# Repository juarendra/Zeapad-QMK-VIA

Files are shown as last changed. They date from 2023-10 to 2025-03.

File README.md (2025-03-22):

# ZEAPAD-QMK-VIA
Zeapad Encoder adalah sebuah macropad yang dmemiliki 14 key dengan Switch MX dan  2 buah Rotary encoder di ujung kanan atas dan ujung kiri atas.

Rotary encoder pada umummnya digunakan untuk melakukan perubahan nilai yang bervariable seperti volume atau brightness.
dengan menyesuaikan firmware sebelumnya. sekarang anda dapat mengedit fungsi dari Rotary Encoder sesuai dengan keinginan anda pada Software VIA Configurator 

support untuk Windows, Linux dan Mac OS

## Table of Content
* [Product Specsification](#product-specsification)
* [Download VIA](#download-via)
* [Autodetect on VIA or you can load JSON File](#Autodetect-on-VIA-or-you-can-load-JSON-File)
* [Link Keycode QMK](#Link-keycode-qmk)
* [Tutorial VIA Usage](#tutorial-via-usage)
* [Cara Setting Knob](#cara-setting-knob)
* [How To use MACRO](#how-to-use-macro)
* [Preview Hardware](#preview-hardware)
* [Preview VIA](#preview-via)
* [Cara Update/Upgrade Firmware](#cara-update/upgrade-firmware)
* [MIDI2LR Usage](#midi2lr-usage)
* [Documentation](#documentation)
  * [Pinout Diagram](#pinout-diagram)
  * [Dimension](#dimension)
  * [BOM](#bom)
  * [Schematic](#schematic)
  * [Example Program](#examples-program)
* [FAQ](#FAQ)

## Product Specsification
- STM32F401 as Microcontroller
- QMK Firmware
- Support VIA, all key and knob can proggrammed
- RGB Underglow
- 4x Layer 
- 16x Switch or 15x Switch + 1 Encoder or 14x Switch + 2 Encoder
- Hotswap Switch
- 3D Case 
- USB type C

## Download VIA
Link Download VIA(Pilih sesuai OS) : https://github.com/the-via/releases/releases
VIA WEB VERSION : https://usevia.app/

## Autodetect on VIA or you can load JSON File
for auto detect on VIA, you just need connect the macropad to your PC and Open VIA in web or apps
or you can connect VIA manually with this step
- Connect your macropad to PC
- Open VIA
- In Tab Setting, enable "Show Design Tab"
- Open Design Tab
- Load file with name "zeapad_via_definitions.json" 
- Open Configure Tab to setting your macropad
- If nothing happend , do it again from first

## Link Keycode QMK
- mouse : https://github.com/qmk/qmk_firmware/blob/master/docs/feature_mouse_keys.md
- keyboard : https://github.com/qmk/qmk_firmware/blob/master/docs/keycodes.md

## Tutorial VIA Usage
- https://docs.keeb.io/via

## Cara Menggunakan Tap Hold dan Tap Reapeatly
### Tap Hold
- Anda perlu mendaftakan satu tombol dahulu yang aakn digunakan sebagai trigger tap hold
- Pilih satu key yang akan digunakkan sebagi trigger Tap Hold
- Pada Setting keymap masuk ke tab "Special" dan pilih "Any Key"
- Masukan "0x7C59" dan tekan OK
- Anda telah memiliki trigger untuk Tap Hold
- Untuk menggunakannya anda dapat menekan dahulu trigger Tap Hold
- lalu tekan tombol lainnya yang ingin di hold terus
- maka tombol tersebut akan tertekan terus sampai anda menekan tombol itu kembali untuk menghentikannya

Note: Untuk Tap hold hanya mendukung tombol biasa seperti tombol "QWERTY"

### Tap Repeatly
- Anda perlu mendaftakan satu tombol dahulu yang aakn digunakan sebagai trigger Tap Repeatly
- Pilih satu key yang akan digunakkan sebagi trigger Tap Repeatly
- Pada Setting keymap masuk ke tab "Special" dan pilih "Any Key"
- Masukan "CUSTOM(85)" dan tekan OK
- Anda telah memiliki trigger untuk Tap Repeatly
- Untuk menggunakannya anda dapat menekan dahulu trigger Tap Repeatly
- lalu tekan tombol lainnya yang ingin di tekan dengan mode Repeatly
- maka tombol tersebut akan tertekan Repeatly dengan delay 100ms sampai anda menekan tombol itu kembali untuk menghentikannya

Note: Untuk Tap Repeatly hanya mendukung tombol biasa seperti tombol "QWERTY" dan "any key"

## Cara Setting Knob
- Untuk melakukan setting di knob perlu memasukan command berupa keycode qmk, Jadi cara nya sama dengan melakuykan setting dengan Any key seperti petunjuk pada link berikut: 
https://docs.keeb.io/via

Here's some examples:

- LALT(KC_TAB) - Sends Alt-Tab
- LCTL(KC_C) - Sends Ctrl-C
- LGUI(KC_C) - Sends Cmd-C or Win-C
- LSFT(LCTL(KC_END)) - Sends Shift-Ctrl-End
- MO(1) - Momentarily turn on layer 1
- LCA(KC_DEL) - Sends Ctrl-Alt-Del
- MT(MOD_RSFT, KC_ENT) - Sends Shift if held, Enter if tapped
- MACRO (0) - macro 0

## How To use MACRO
you can read on [this file](https://github.com/juarendra/STREAMPAD-QMK-VIA/blob/main/DOC/MACRO%20VIA%20USAGE.pdf)
or you can read on this [web](https://www.keychron.com/blogs/archived/how-to-use-via-to-program-your-keyboard)
or you can see video [youtube](https://youtu.be/GtSeo69Y0Zw)

## Preview Hardware
<p align="center">
  
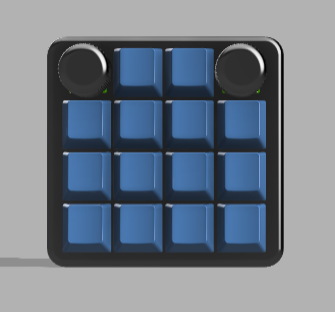
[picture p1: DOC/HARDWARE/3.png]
  
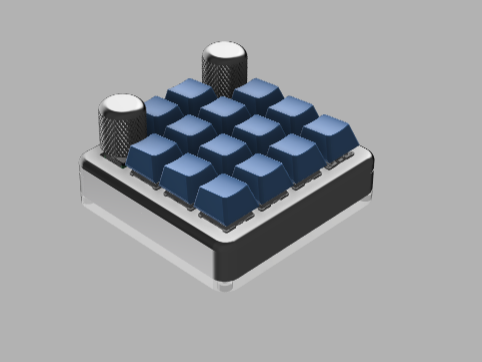
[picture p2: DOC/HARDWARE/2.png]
  
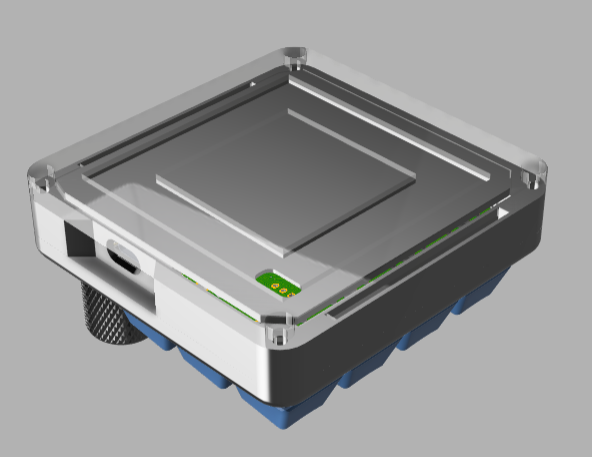
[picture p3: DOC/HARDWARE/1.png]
  
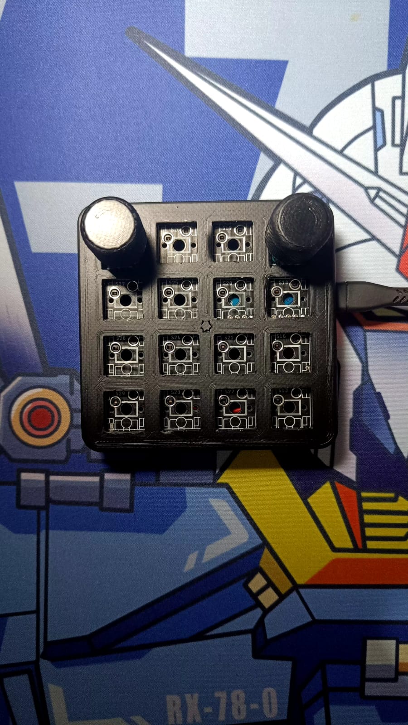
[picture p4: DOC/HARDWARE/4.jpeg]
  
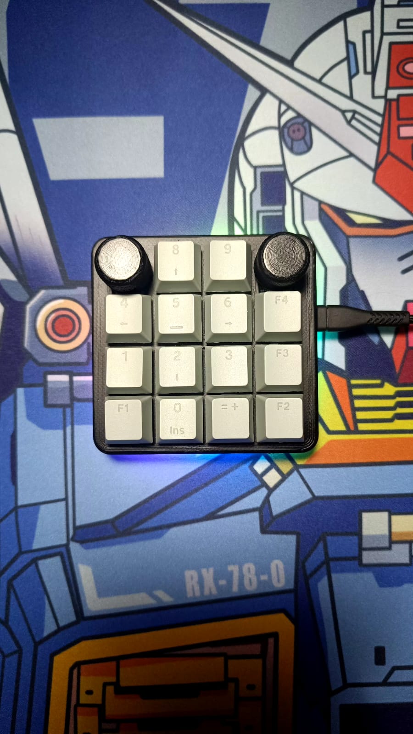
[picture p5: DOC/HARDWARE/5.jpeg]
  
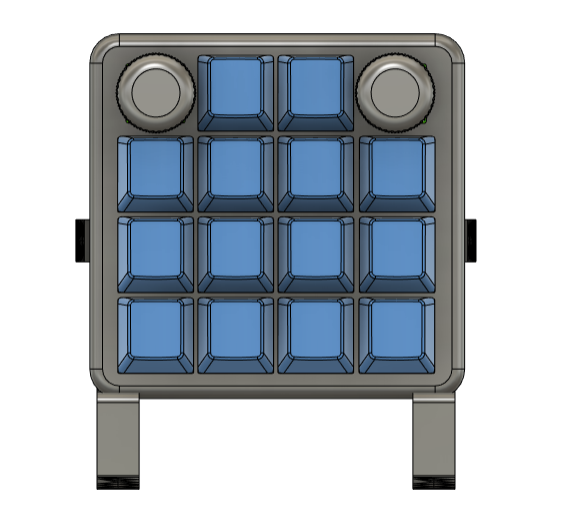
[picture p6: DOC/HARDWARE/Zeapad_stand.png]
  
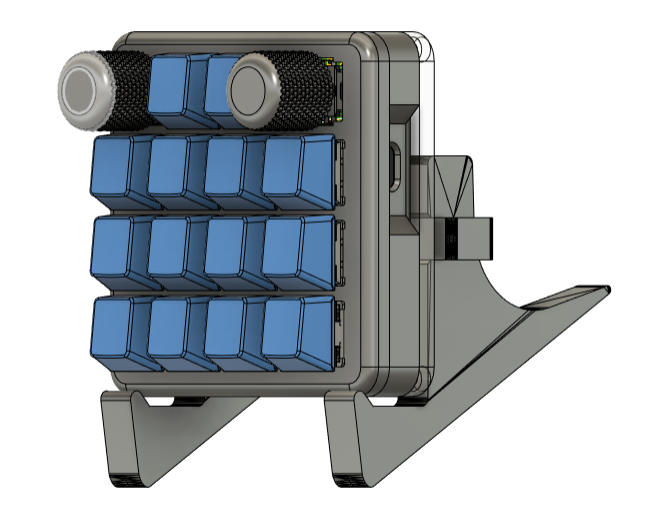
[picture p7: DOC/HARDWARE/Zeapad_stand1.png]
  
</p>

## Preview VIA
Positron Electronic on YouTube (http://www.youtube.com/watch?v=qvMjg3LCvkY "zeapad stm32")

## Cara Update/Upgrade Firmware
- Siapkan dahulu macropad, kabel usb dan firmware yang ingin di update/upgrade ke macropad anda
- Siapkan Firmware yang akan digunakan untuk update/upgrade
- Download Software QMK Toolbox di [link berikut](https://github.com/qmk/qmk_toolbox/releases)
- Install Software QMK Toolbox, Install Semua drivernya. setelah siap anda dapat meload Firmware yang seblumnya. Lalu Centang Auto-Flash seperti gambar dibawah
<p align="center">
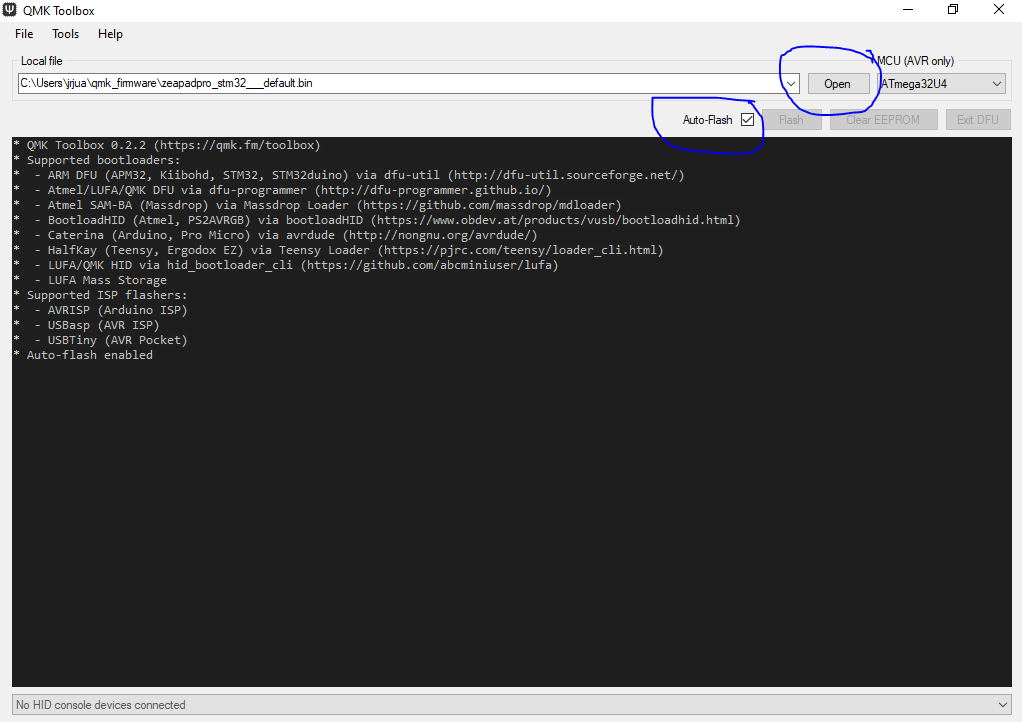
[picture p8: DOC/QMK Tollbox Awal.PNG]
  
</p>

- Colok kabel ujung usb type C ke macropad tanpa mencolokannya dahulu ke USB PC anda
- Tekan dan tahan tombol/knob yang berada di ujung atas kiri. lalu colokan Ujung USB yang sebelum ke USB PC anda sambil tetap menahan tombol sebelum nya sebentar
- Setelah ada bunyi/notif USB masuk. anda dapat melepaskan tombol/knobnya
- Maka secara otomatis macropad akan terflash. jika selesai maka tampilan QMK toolbox akan seperti gambar dibawah
<p align="center">
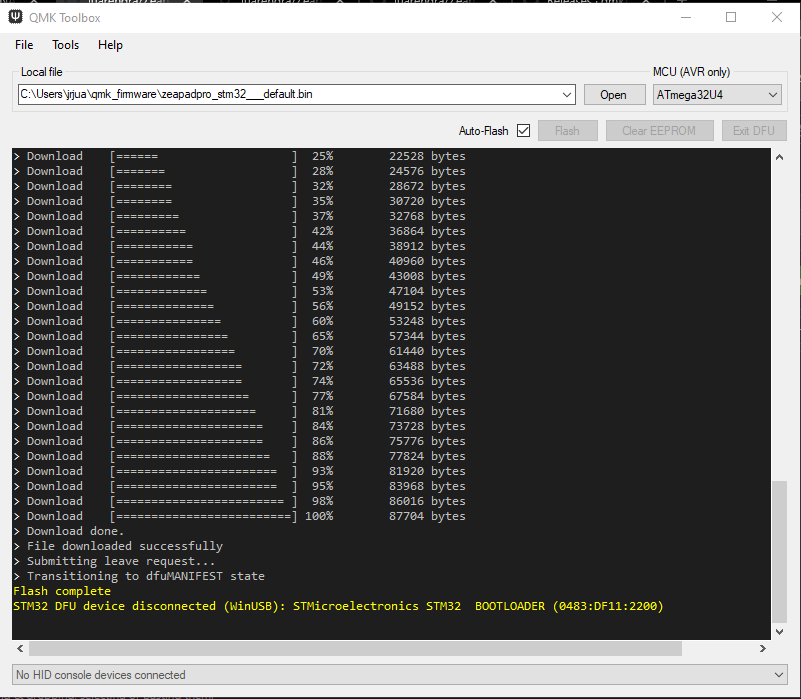
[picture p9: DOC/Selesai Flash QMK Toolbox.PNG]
  
</p>

## MIDI2LR Usage
MIDI2LR adalah extension dari Adobe Ligtroom yang berguna untuk mengkonversi inputan MIDI dari Midi controller menjadi perintah perintah Lightroom. Salah satu fitur QMK adalah dapat dijadikan sebuah midi controller, sehingga pada dibutalah firmware QMK yang dapat mendukung fitur midi controller pada macropad ZEAPAD PRO tersebut. 

untuk mempelajari penggunaan MIDI2LR and dapat melihat VIDEO [berikut](https://www.youtube.com/watch?v=VDSN_Vz6U04&t=319s).

untuk menggunakan zeapad pro sebagai midi controller anda dapat memasukan keycode midi controller yang ada di link [berikut](https://docs.qmk.fm/features/midi) ke ANY KEY pada aplikasi VIA, seprti contohnya keycode "MI_C" untuk mengirimkan note C, "MI_D" untuk mengirimkan note D

Untuk mengirimkan CC atau Control Change anda dapat memasukan keycode pada TAB "Custom" di aplikasi VIA seperti gambar dibawah

<p align="center">
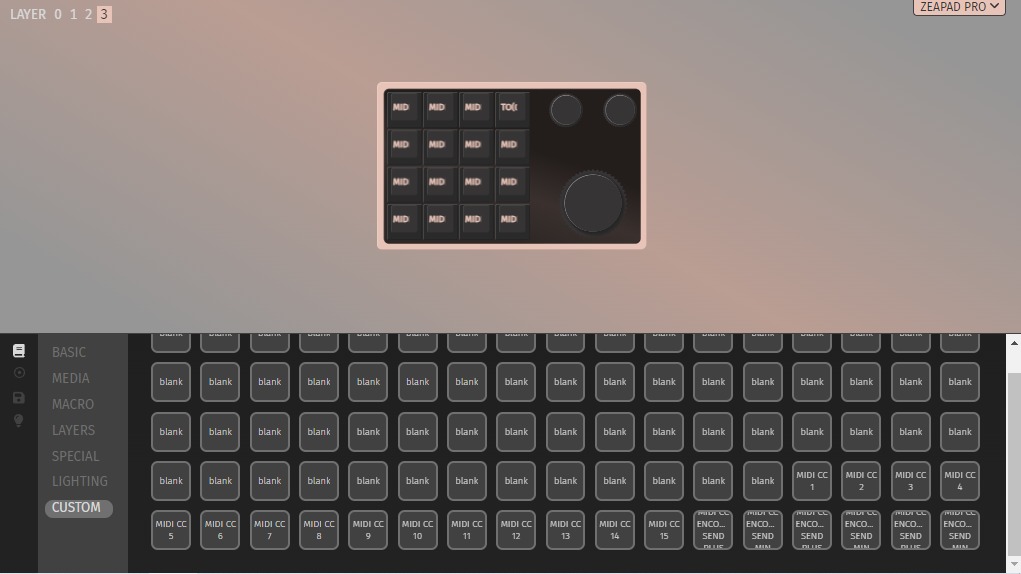
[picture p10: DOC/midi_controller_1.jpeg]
  
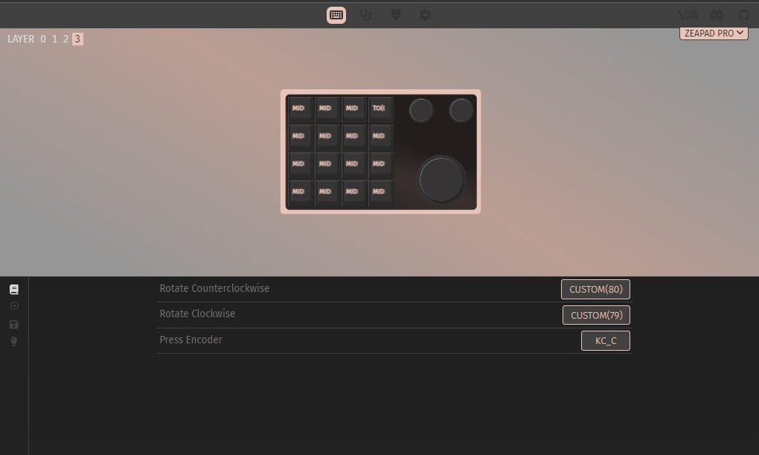
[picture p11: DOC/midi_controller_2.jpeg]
  
</p>

berikut merupakan penjelasan keycode keycode yang ada pada TAB "Custom". abaikan keycode dengan nama "blank". Semua keycode dibawah ini sudah di lakukan preset di layer ke 4

| Keycode | Function |  Penjelasana | 
| --- | --- | --- |
| MIDI CC 1  | Memilih CC 1 untuk encoder 1, CC 16 untuk encoder 2 dan CC 31 untuk encoder 3| dengan menekan keycode ini anda akan memilihi CC tersebut sehingga pada saat anda memutar knob/encoder yang berkaitan maka akan mengirimkan CC yang terpilih sebelumnya sesuai dengan encoder/knob yang di putar|
| MIDI CC 2  | Memilih CC 2 untuk encoder 1, CC 17 untuk encoder 2 dan CC 32 untuk encoder 3| dengan menekan keycode ini anda akan memilihi CC tersebut sehingga pada saat anda memutar knob/encoder yang berkaitan maka akan mengirimkan CC yang terpilih sebelumnya sesuai dengan encoder/knob yang di putar|
| MIDI CC 3  | Memilih CC 3 untuk encoder 1, CC 18 untuk encoder 2 dan CC 33 untuk encoder 3| dengan menekan keycode ini anda akan memilihi CC tersebut sehingga pada saat anda memutar knob/encoder yang berkaitan maka akan mengirimkan CC yang terpilih sebelumnya sesuai dengan encoder/knob yang di putar|
| MIDI CC 4  | Memilih CC 4 untuk encoder 1, CC 19 untuk encoder 2 dan CC 34 untuk encoder 3| dengan menekan keycode ini anda akan memilihi CC tersebut sehingga pada saat anda memutar knob/encoder yang berkaitan maka akan mengirimkan CC yang terpilih sebelumnya sesuai dengan encoder/knob yang di putar|
| MIDI CC 5  | Memilih CC 5 untuk encoder 1, CC 20 untuk encoder 2 dan CC 35 untuk encoder 3| dengan menekan keycode ini anda akan memilihi CC tersebut sehingga pada saat anda memutar knob/encoder yang berkaitan maka akan mengirimkan CC yang terpilih sebelumnya sesuai dengan encoder/knob yang di putar|
| MIDI CC 6  | Memilih CC 6 untuk encoder 1, CC 21 untuk encoder 2 dan CC 36 untuk encoder 3|  dengan menekan keycode ini anda akan memilihi CC tersebut sehingga pada saat anda memutar knob/encoder yang berkaitan maka akan mengirimkan CC yang terpilih sebelumnya sesuai dengan encoder/knob yang di putar|
| MIDI CC 7  | Memilih CC 7 untuk encoder 1, CC 22 untuk encoder 2 dan CC 37 untuk encoder 3|  dengan menekan keycode ini anda akan memilihi CC tersebut sehingga pada saat anda memutar knob/encoder yang berkaitan maka akan mengirimkan CC yang terpilih sebelumnya sesuai dengan encoder/knob yang di putar|
| MIDI CC 8  | Memilih CC 8 untuk encoder 1, CC 23 untuk encoder 2 dan CC 38 untuk encoder 3|  dengan menekan keycode ini anda akan memilihi CC tersebut sehingga pada saat anda memutar knob/encoder yang berkaitan maka akan mengirimkan CC yang terpilih sebelumnya sesuai dengan encoder/knob yang di putar|
| MIDI CC 9  | Memilih CC 9 untuk encoder 1, CC 24 untuk encoder 2 dan CC 39 untuk encoder 3|  dengan menekan keycode ini anda akan memilihi CC tersebut sehingga pada saat anda memutar knob/encoder yang berkaitan maka akan mengirimkan CC yang terpilih sebelumnya sesuai dengan encoder/knob yang di putar|
| MIDI CC 10  | Memilih CC 10 untuk encoder 1, CC 25 untuk encoder 2 dan CC 40 untuk encoder 3|  dengan menekan keycode ini anda akan memilihi CC tersebut sehingga pada saat anda memutar knob/encoder yang berkaitan maka akan mengirimkan CC yang terpilih sebelumnya sesuai dengan encoder/knob yang di putar|
| MIDI CC 11  | Memilih CC 11 untuk encoder 1, CC 26 untuk encoder 2 dan CC 41 untuk encoder 3|  dengan menekan keycode ini anda akan memilihi CC tersebut sehingga pada saat anda memutar knob/encoder yang berkaitan maka akan mengirimkan CC yang terpilih sebelumnya sesuai dengan encoder/knob yang di putar|
| MIDI CC 12  | Memilih CC 12 untuk encoder 1, CC 27 untuk encoder 2 dan CC 42 untuk encoder 3|  dengan menekan keycode ini anda akan memilihi CC tersebut sehingga pada saat anda memutar knob/encoder yang berkaitan maka akan mengirimkan CC yang terpilih sebelumnya sesuai dengan encoder/knob yang di putar|
| MIDI CC 13  | Memilih CC 13 untuk encoder 1, CC 28 untuk encoder 2 dan CC 43 untuk encoder 3|  dengan menekan keycode ini anda akan memilihi CC tersebut sehingga pada saat anda memutar knob/encoder yang berkaitan maka akan mengirimkan CC yang terpilih sebelumnya sesuai dengan encoder/knob yang di putar|
| MIDI CC 14  | Memilih CC 14 untuk encoder 1, CC 29 untuk encoder 2 dan CC 44 untuk encoder 3|  dengan menekan keycode ini anda akan memilihi CC tersebut sehingga pada saat anda memutar knob/encoder yang berkaitan maka akan mengirimkan CC yang terpilih sebelumnya sesuai dengan encoder/knob yang di putar|
| MIDI CC 15  | Memilih CC 15 untuk encoder 1, CC 30 untuk encoder 2 dan CC 45 untuk encoder 3|  dengan menekan keycode ini anda akan memilihi CC tersebut sehingga pada saat anda memutar knob/encoder yang berkaitan maka akan mengirimkan CC yang terpilih sebelumnya sesuai dengan encoder/knob yang di putar|
| MIDI CC ENCODER1 SEND PLUS  | Mengirimkan CC yang terpilih untuk encoder/knob 1 dengan value 65 | keycode ini perlu di daftarkan ke encoder/knob pada orientasi clockwise agar dapat mengatur menaikan value CC yang sesuai di encoder/ knob 1 |
| MIDI CC ENCODER1 SEND MIN  | Mengirimkan CC yang terpilih untuk encoder/knob 1 dengan value 63 | keycode ini perlu di daftarkan ke encoder/knob pada orientasi anticlockwise agar dapat mengatur menaikan value CC yang sesuai di encoder/ knob 1 |
| MIDI CC ENCODER2 SEND PLUS  | Mengirimkan CC yang terpilih untuk encoder/knob 2 dengan value 65 | keycode ini perlu di daftarkan ke encoder/knob pada orientasi clockwise agar dapat mengatur menaikan value CC yang sesuai di encoder/ knob 2 |
| MIDI CC ENCODER2 SEND MIN  | Mengirimkan CC yang terpilih untuk encoder/knob 2 dengan value 63 | keycode ini perlu di daftarkan ke encoder/knob pada orientasi anticlockwise agar dapat mengatur menaikan value CC yang sesuai di encoder/ knob 2  |
| MIDI CC ENCODER3 SEND PLUS  | Mengirimkan CC yang terpilih untuk encoder/knob 3 dengan value 65 | keycode ini perlu di daftarkan ke encoder/knob pada orientasi clockwise agar dapat mengatur menaikan value CC yang sesuai di encoder/ knob 3 |
| MIDI CC ENCODER3 SEND MIN  | Mengirimkan CC yang terpilih untuk encoder/knob 3 dengan value 63| keycode ini perlu di daftarkan ke encoder/knob pada orientasi anticlockwise agar dapat mengatur menaikan value CC yang sesuai di encoder/ knob 2 |

## Documentation
### Pinout Diagram
### Dimension
[Dimension File](https://github.com/juarendra/Zeapad-QMK-VIA/blob/main/HARDWARE/zeapad_dimension.pdf)
### BOM
### Schematic
[Schematic File](https://github.com/juarendra/Zeapad-QMK-VIA/blob/main/HARDWARE/zeapad_stm32.pdf)
### Example Program
[Example Firmware](https://github.com/juarendra/Zeapad-QMK-VIA/tree/main/FIRMWARE)
## FAQ

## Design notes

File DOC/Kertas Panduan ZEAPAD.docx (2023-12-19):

1. Untuk Documentasi Lengkapnya anda dapat membuka link google drive dibawah ini

https://shorturl.at/cdsA3

2. Lihat dahulu video untuk mengetahui cara pengunaan macropad dengan software VIA
3. Fungsi file file di google drive
a. Link Keycode.txt = berisi link yang menunjukan list keycode yang dapat digunakan dalam melakukan setting keymap
b. TUTORIAL MACRO ON VIA CONFIGURATOR.txt = berisi link tutorial cara membuat macro di software via
c. LINK TUTORIAL PENGGUNAAN.txt = berisi link video tutorial penggunaan
d. TUTORIAL MEMBUAT TOMBOL PINDAH LAYER.txt = berisi panduan untuk merubah fungsi tombol sebagai trigger memindahkan layer
e. zeapad_via_definitions.json = File json yang perlu dimasukkan ke VIA

Untuk panduan lainnya menggunakan software via ada dapat membacanya disini https://docs.keeb.io/via

Pada via hanya dapat menyimpan maks 15 macro di seluruh layer. Ada beberapa trik untuk memaksimalkannya. Jika macro anda hanya kombinasi sederhana seperti CTRL + ALT + DEL maka anda dapat menggunakan fitur ANY keys pada tab special seperti dibawah

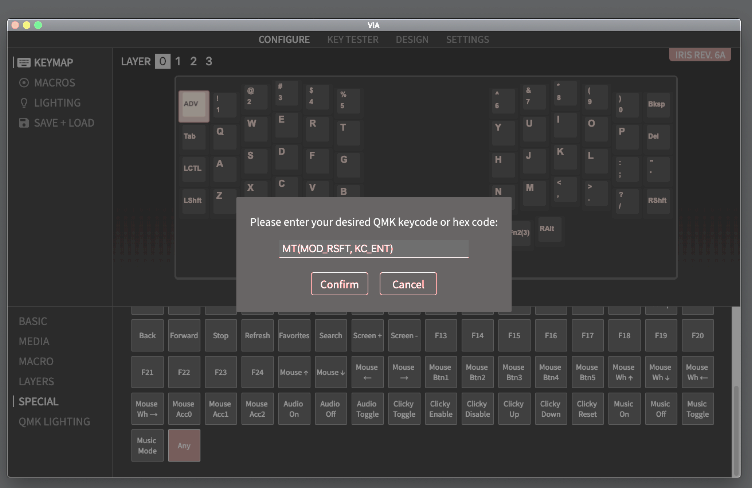
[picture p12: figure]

Untuk jelasnya anda dapat membacanya di https://docs.keeb.io/via

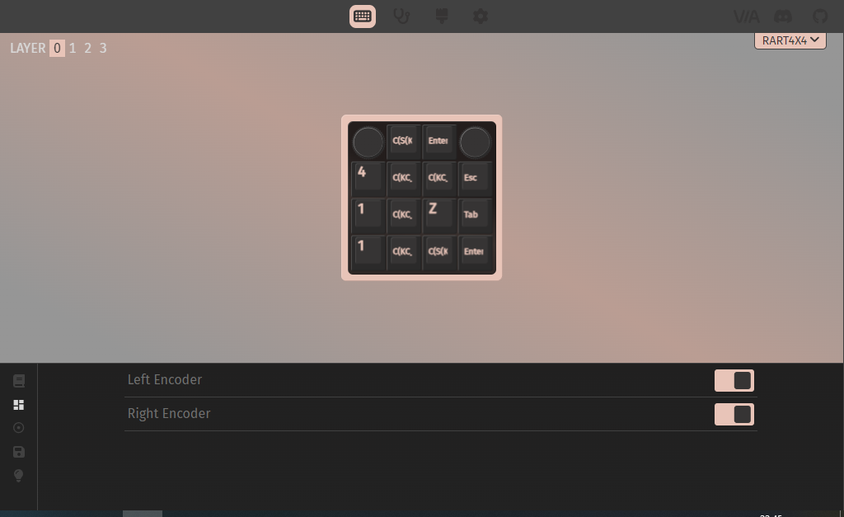
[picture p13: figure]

Anda harus mengaktiflkan kedua encoder untuk melakukan setting pada putaran encoder seperti pada gambar

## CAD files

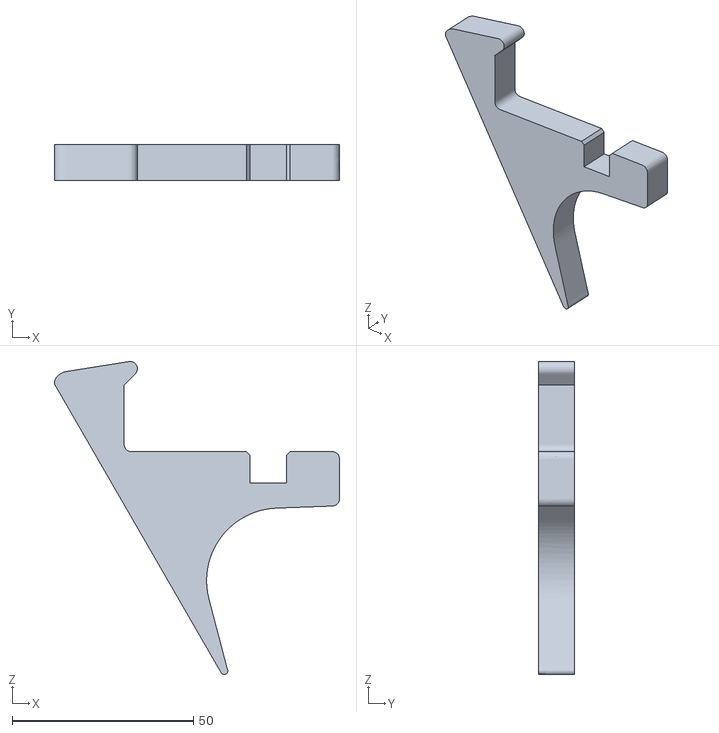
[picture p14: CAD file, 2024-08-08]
HARDWARE/Case/stand/Revised_Keyboard_Stand_Legs_v02 (5).stl
78.6 x 10.0 x 86.3

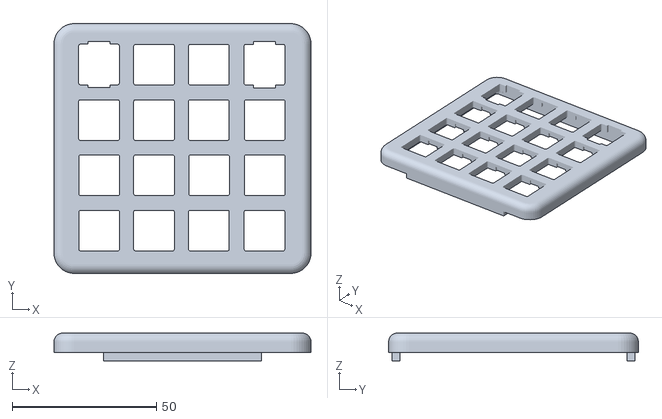
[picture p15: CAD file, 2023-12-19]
HARDWARE/Case/top_zeapad_stm32.stl
89.0 x 86.5 x 9.66

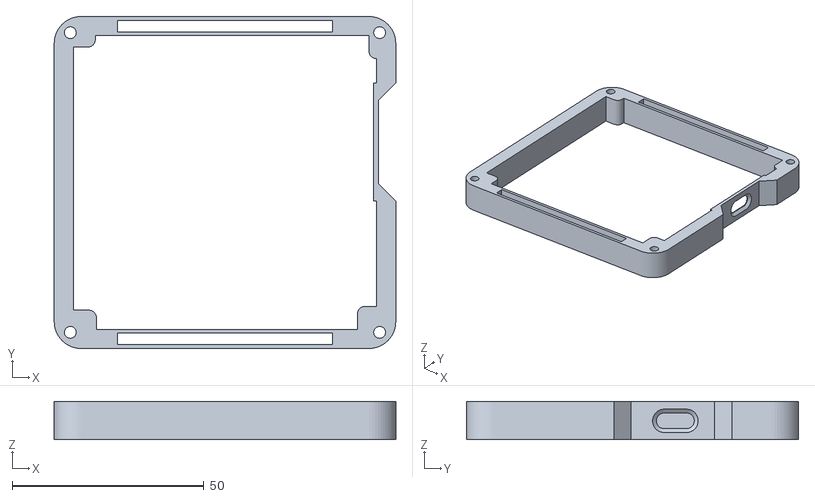
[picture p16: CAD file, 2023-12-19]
HARDWARE/Case/middle_zeapad_stm32.stl
89.0 x 86.5 x 10.0

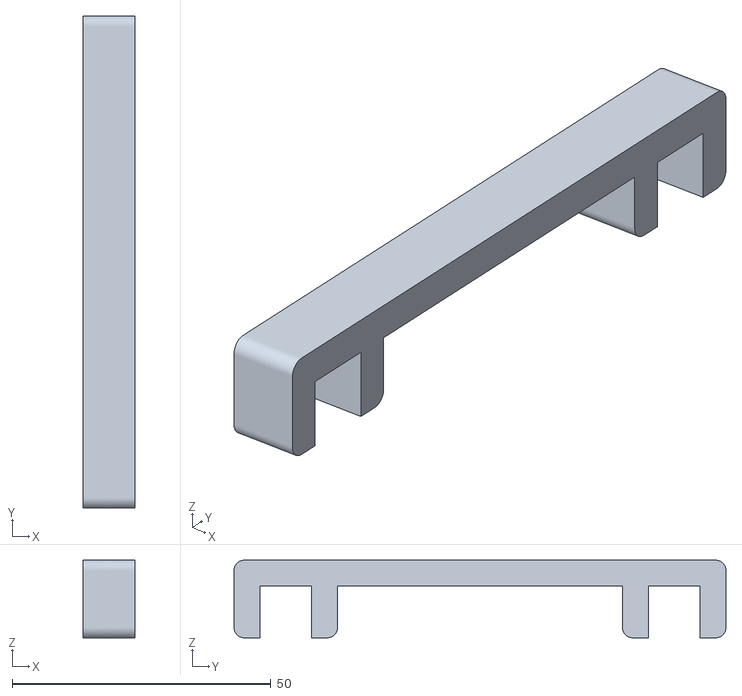
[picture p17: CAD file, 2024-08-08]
HARDWARE/Case/stand/Support (1) (1).stl
10.0 x 95.0 x 15.0

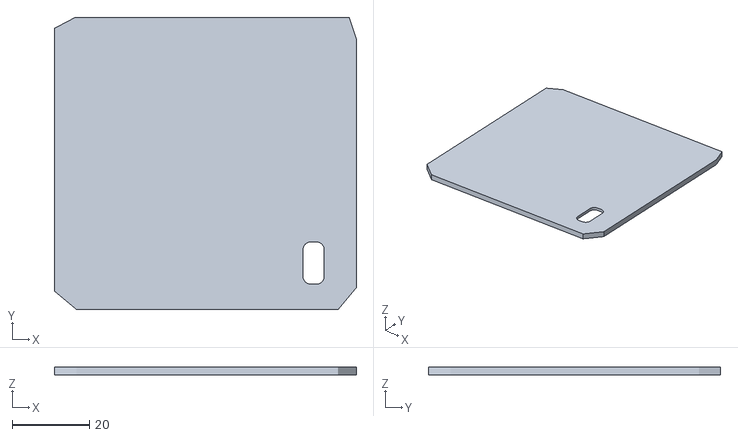
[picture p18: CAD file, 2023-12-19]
HARDWARE/Case/braket_led_stm32.stl
78.2 x 75.7 x 2.00

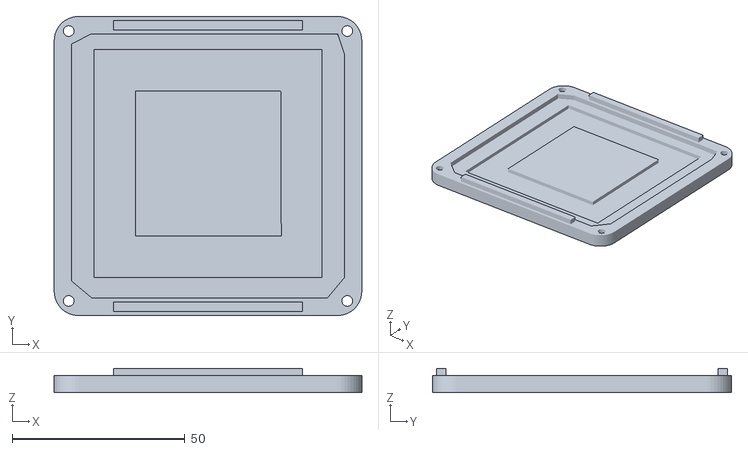
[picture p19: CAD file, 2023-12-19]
HARDWARE/Case/bottom_zeapad_stm32.stl
89.0 x 86.5 x 7.00

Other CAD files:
HARDWARE/Case/stand/Revised_Keyboard_Stand_Legs_v02 (5) (1).stl

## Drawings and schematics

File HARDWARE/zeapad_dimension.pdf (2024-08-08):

86.5
46.01 35.51

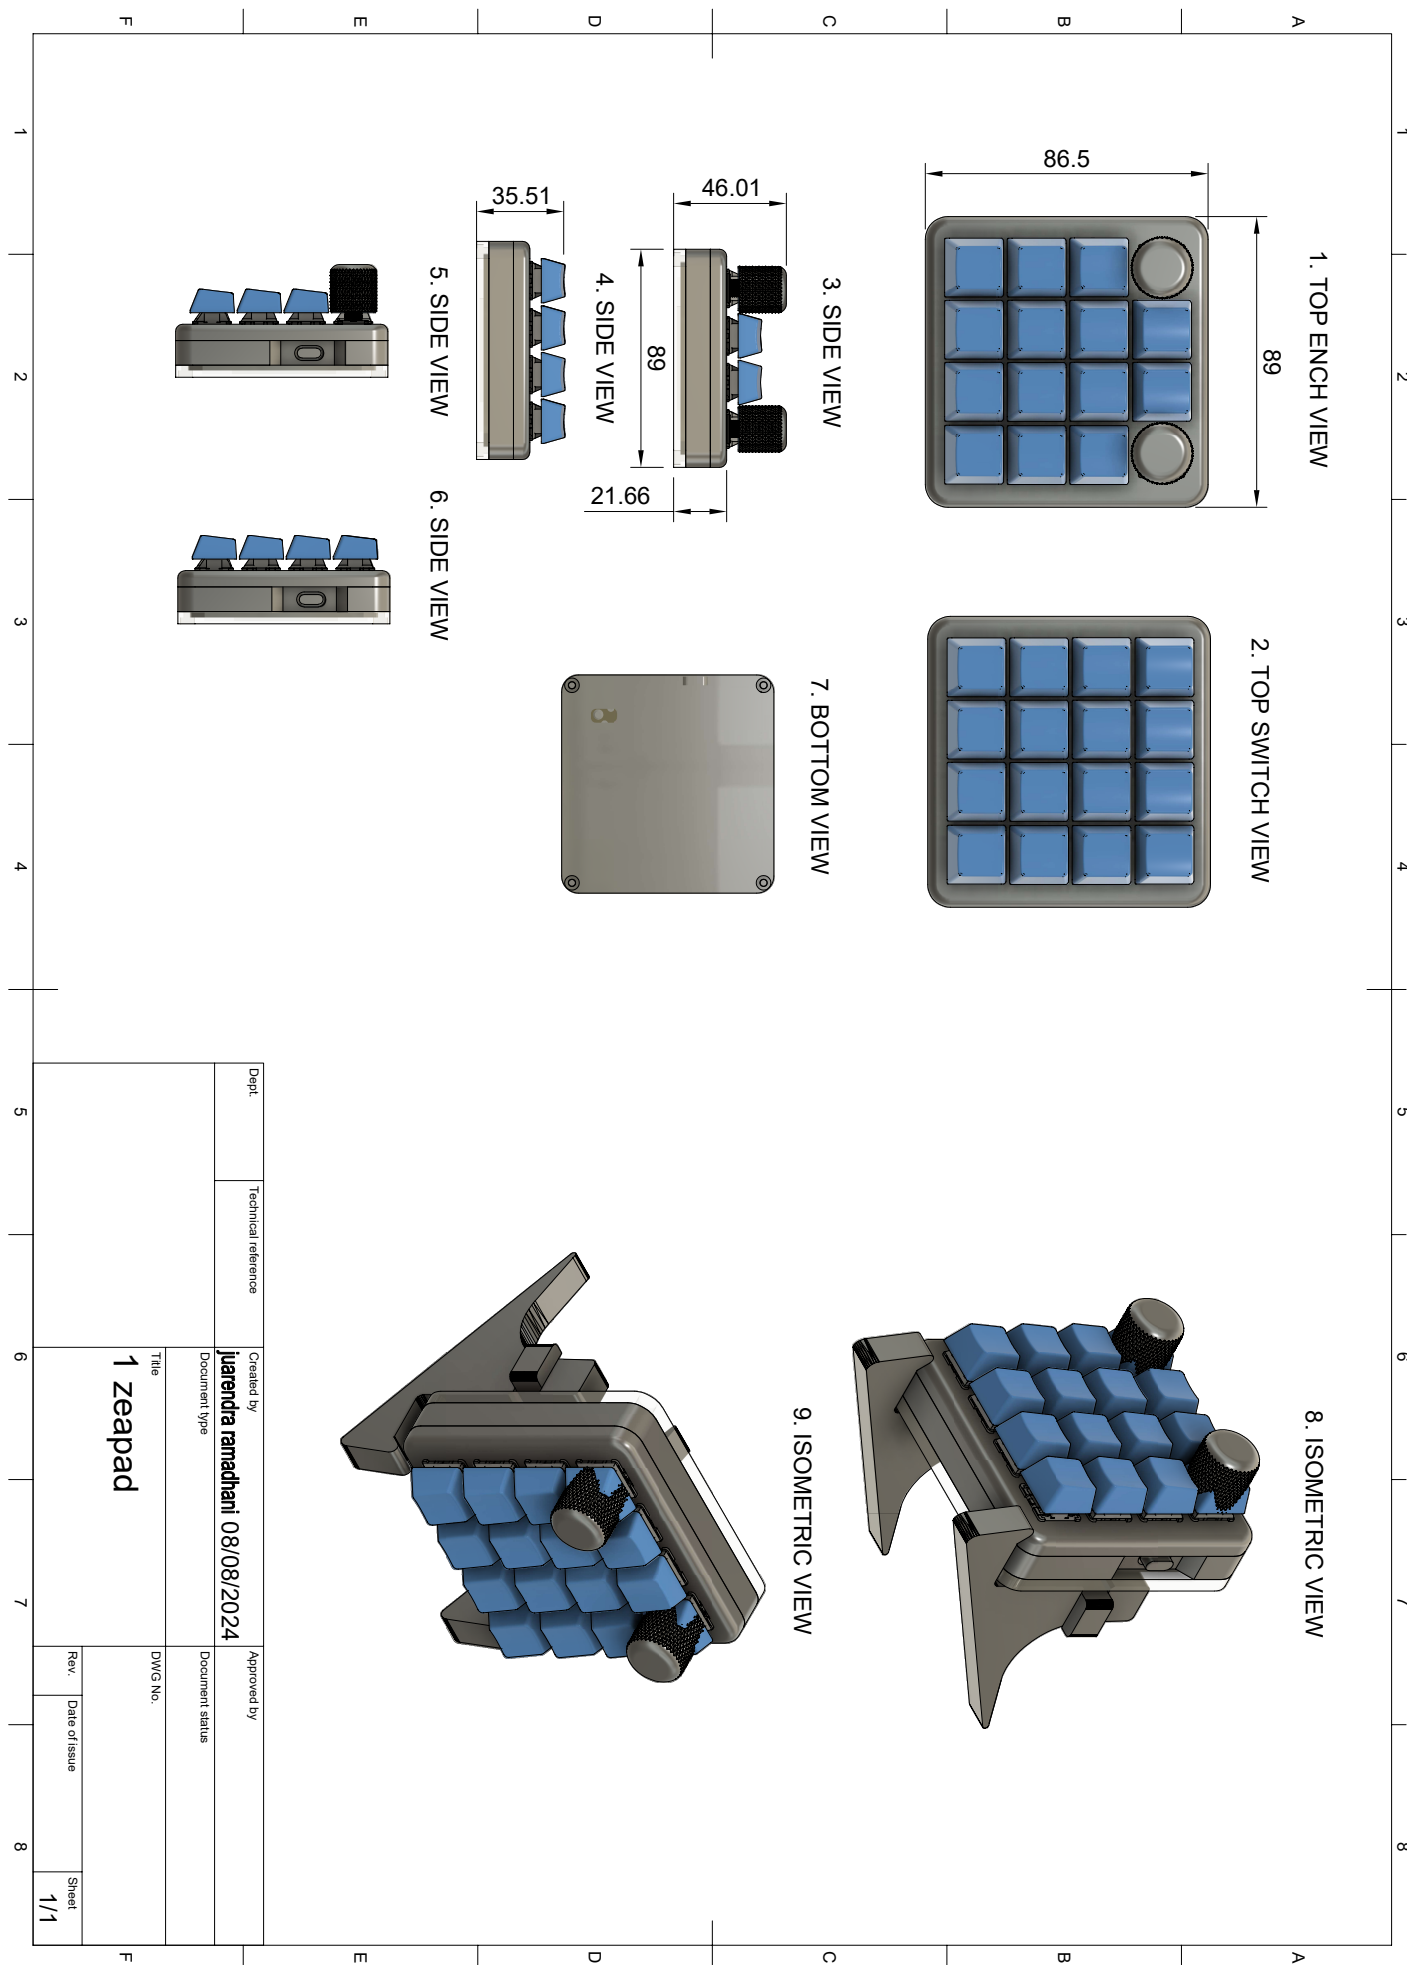
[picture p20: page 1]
1. TOP ENCH VIEW 2. TOP SWITCH VIEW ⁵. SIDE VIEW 6. SIDE VIEW; 4. SIDE VIEW; 3. SIDE VIEW 7. BOTTOM VIEW 9. ISOMETRIC VIEW; 8. ISOMETRIC VIEW

1 A 2 3 4 5 6 7 8 1 2 3 4 5 6 7 8 FEDCB FEDCBA Dept. Technical reference Created by Approved by Title DWG No. Document type Document status Rev. Date of issue Sheet 08/08/2024 1/1 1 zeapad 89

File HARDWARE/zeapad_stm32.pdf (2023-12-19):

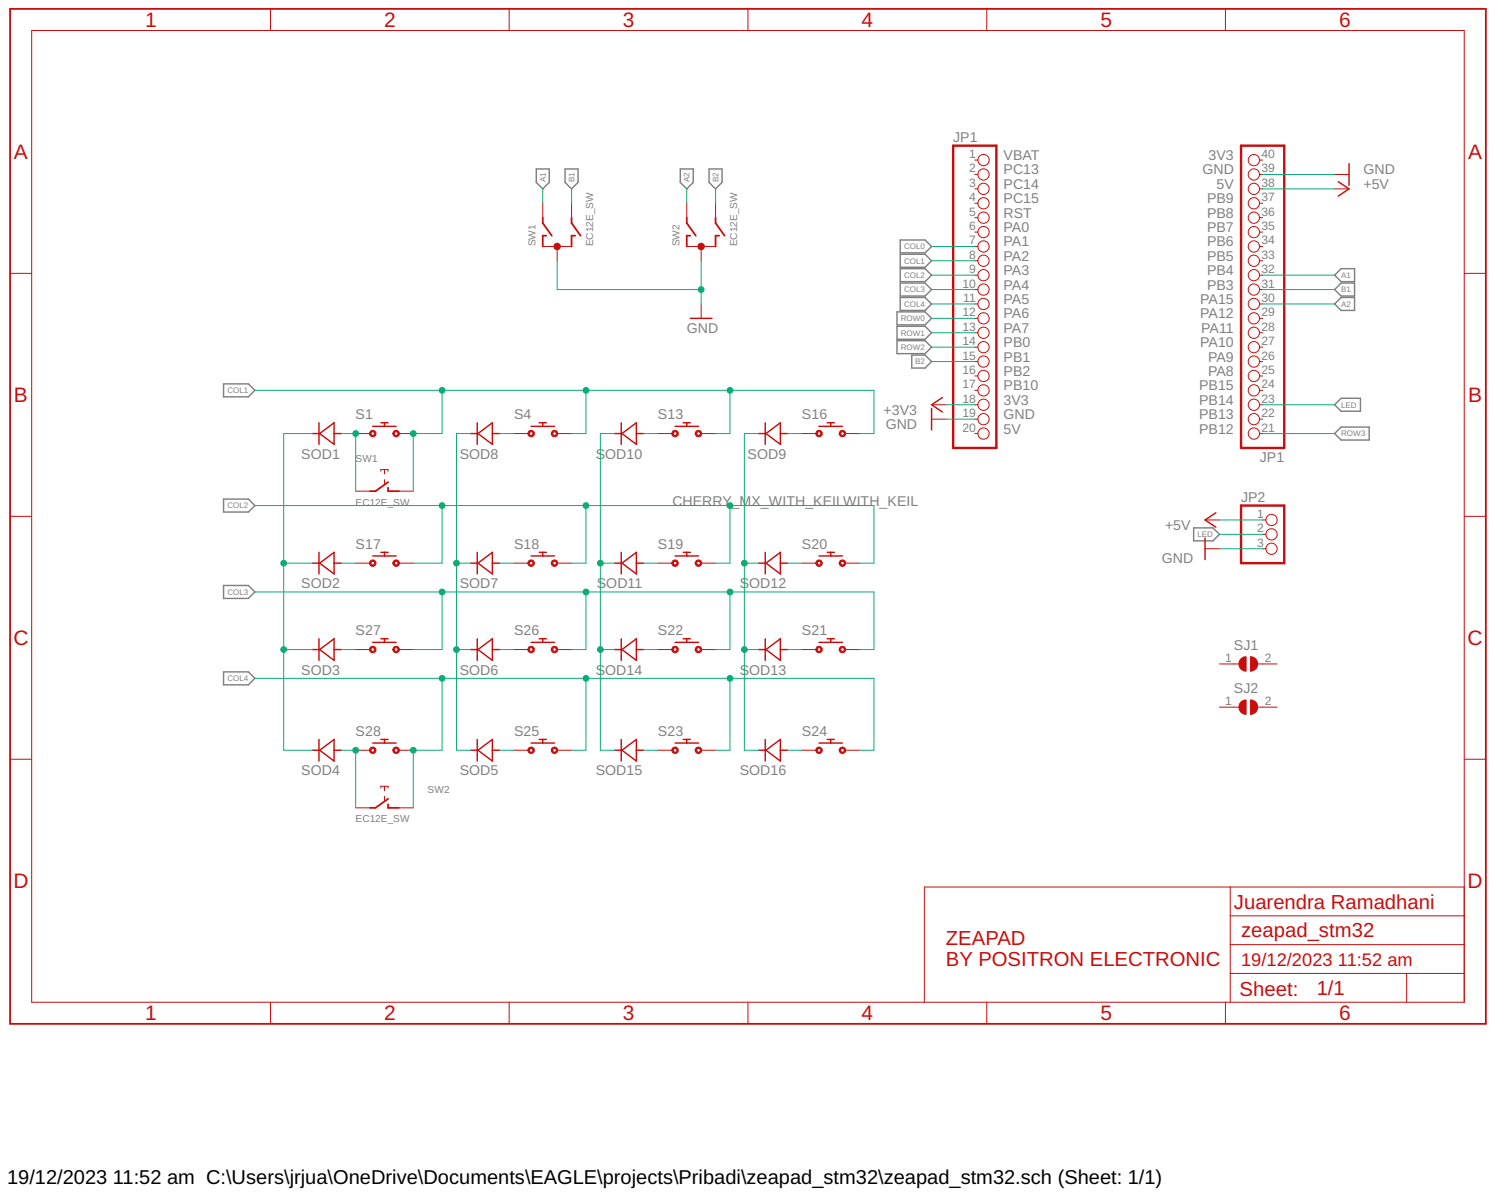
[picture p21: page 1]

19/12/2023 11:52 am C:\Users\jrjua\OneDrive\Documents\EAGLE\projects\Pribadi\zeapad_stm32\zeapad_stm32.sch (Sheet: 1/1)

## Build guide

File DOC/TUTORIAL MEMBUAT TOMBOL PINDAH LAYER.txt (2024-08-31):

1. Buka App VIA Configurator
2. Masukan File JSON keymap yang ada di google drive
3. Hubungkan Macropad ke PC
4. Buka Tab Configure
5. Pada Tab Configure pilih Tab Layer
6. Tentukan 1 Tombol yang akan digunakan untuk perpindahan layer
7. Ketika baru pertama dihubungkan ke PC maka macropad otomatis berada pada layer 0, 
8. Klick tombol tersebut dan ganti fungsi menjadi T01(isi dari tab layer), ini artinya fungsi tombol tersebut adalah memidahkan layer sekarang ke layer 1
9. Pindah ke layer 1, lalu klick tombol tersebut lagi dan ganti fungsi menjadi TO2(isi dari tab layer), ini artinya fungsi tombol tersebut adalah memidahkan layer sekarang ke layer 2
10.Pindah ke layer 2, lalu klick tombol tersebut lagi dan ganti fungsi menjadi TO3(isi dari tab layer), ini artinya fungsi tombol tersebut adalah memidahkan layer sekarang ke layer 3
11. Pindah ke layer 3, lalu klick tombol tersebut lagi dan ganti fungsi menjadi TO0(isi dari tab layer), ini artinya fungsi tombol tersebut adalah memindahkan layer sekarang kembali lagi ke layer 0
12. Selesai

layer 0 ----> layer 1 ----> layer 2 ----> layer 3 ----> layer 0
	 TO1	      TO2            TO3            TO0

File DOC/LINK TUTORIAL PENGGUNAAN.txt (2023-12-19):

Cara Menggunakan Software VIA Pada Macropad
1. Colok dahulu Macropad pada PC
2. Buka Aplikasi VIA
3. Pada Tab Setting , aktifkan “Show Design Tab”
4. Buka Tan Design
5. Load file extension “json” di google drive yang di berikan
6. Buka tab Configure untuk melakukan setting
7. Jika masih muncul gambar searching, maka ulangi lagi load json file

Lakukan Hal ini setiap kali ingin setting macropad di VIA

video tutorial: 
https://youtu.be/hh9AlTF5bT8

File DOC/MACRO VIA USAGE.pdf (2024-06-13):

MACRO
Pada VIA memiliki space yang terbatas atau jumlah macro yang tebatas. Maka dari itu untuk memaksimalkan penggunaan, anda dapat menggunkan Fitur Any Key jika macro anda hanya terdiri dari kombinasi yang sederhana. Untuk saat ini tidak ada batasan pada penggunaan Fitur Any Key
- MACRO NORMAL
Jika anda akan membuat macro dengan kombinasi yang rumit, anda dapat menggunakan macro yang ada pada tab/menu MACRO seperti gambar dibawah.
Macro Recorder

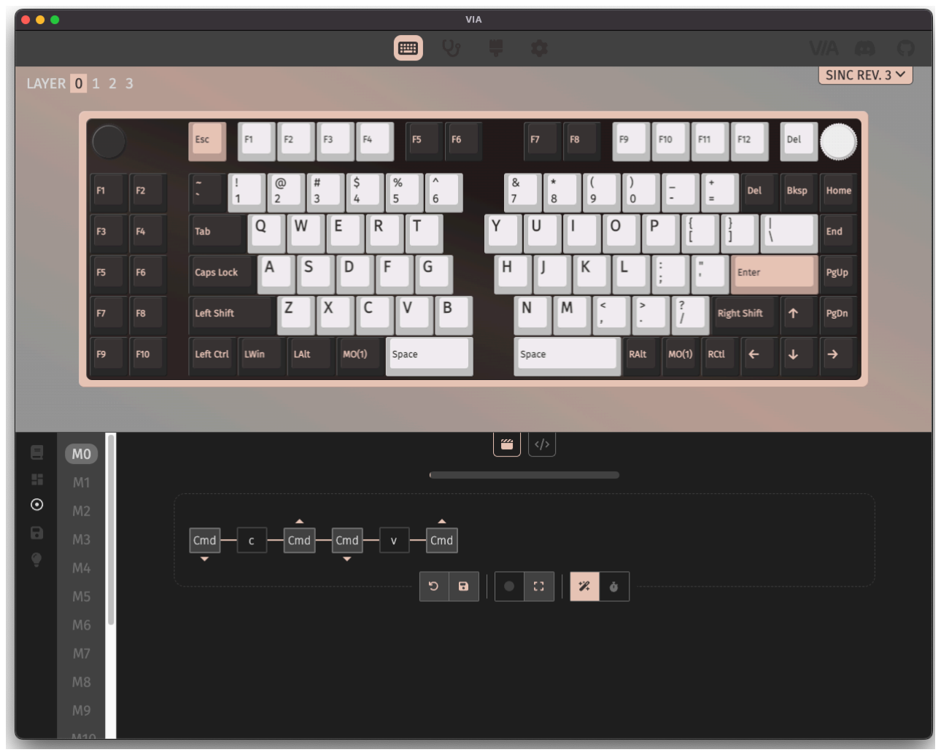
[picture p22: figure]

Metode ini memungkinkan Anda merekam makro, alih-alih mencoba mengetikkan kode kunci secara manual.
Keycode Entry

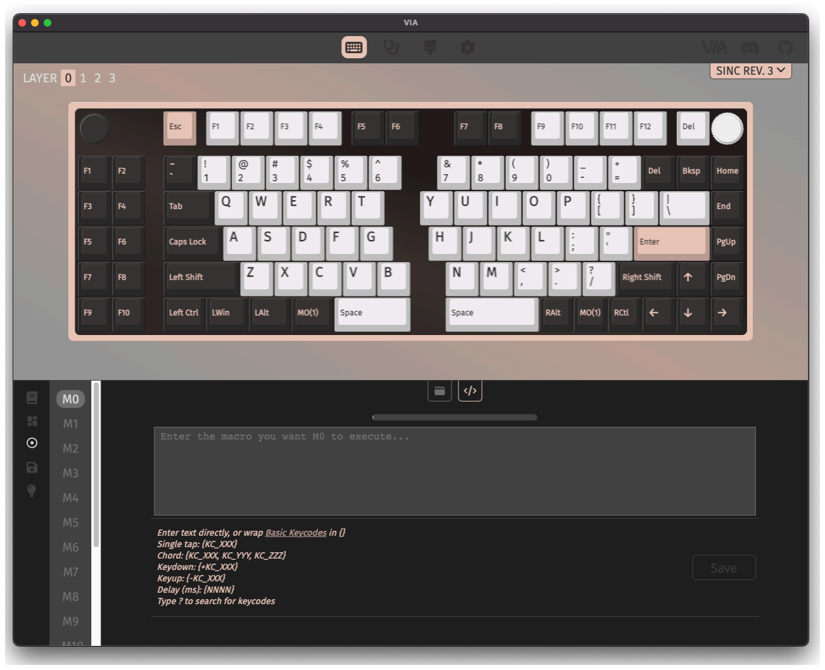
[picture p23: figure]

Anda bisa mengetik teks secara langsung tanpa harus mengetahui apa pun tentang nama keycodei QMK, atau jika Anda memasukkan sesuatu ke dalam tanda kurung kurawal ({}), Anda bisa menggunakan kode kunci QMK dasar.

Beberapa istilah yang perlu diketahui

MO (lapisan): Ini mengaktifkan lapisan ketika ditekan dan Anda kembali ke lapisan sebelumnya ketika Anda melepaskan kunci. Mirip dengan tombol Shift dan Fn dalam pengoperasiannya.

LM(layer, modifier): Ini mengaktifkan lapisan dan juga akan mempertahankan pengubah untuk Anda saat ditekan.

LT(lapisan, kode kunci): Tekan ini dan tahan untuk mengaktifkan lapisan dan mengirimkan kode kunci ketika diketuk sebentar. Penggunaan terbaik untuk tombol yang biasanya hanya Anda tekan dengan cepat seperti Tab atau Spasi.

Contoh Makro
MyPassw0rd! - Mengirim MyPassw0rd!
{KC_A,KC_C,KC_E} - Mengirim kartu as
{KC_LCTL,KC_C} - Mengirim Ctrl-C
- Any Key
Any Key dapat digunakan untuk melakukan beberapa kode kunci yang lebih kompleks, seperti yang melibatkan pengubah, lapisan, atau tombol ketuk mod. Anda juga dapat memasukkan kode kunci biasa di sini jika Anda mau.

Tidak semua alias didukung, misalnya LCTL_T(kc) tidak dapat digunakan, jadi MT(MOD_LCTL, kc) harus digunakan.

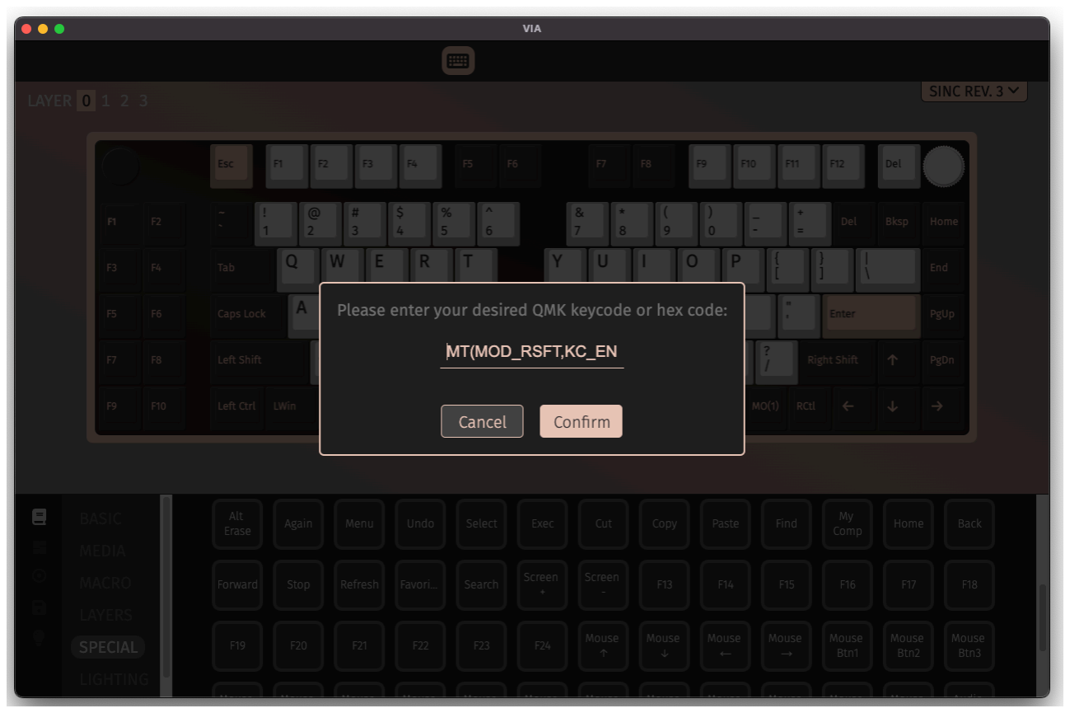
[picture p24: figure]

Here's some examples:

LALT(KC_TAB) - Sends Alt-Tab
LCTL(KC_C) - Sends Ctrl-C
LGUI(KC_C) - Sends Cmd-C or Win-C LSFT(LCTL(KC_END)) - Sends Shift-Ctrl-End
MO(1) - Momentarily turn on layer 1
LCA(KC_DEL) - Sends Ctrl-Alt-Del
MT(MOD_RSFT, KC_ENT) - Sends Shift if held, Enter if tapped QMK Lighting

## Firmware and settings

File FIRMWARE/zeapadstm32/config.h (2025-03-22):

/* Copyright 2024 Juarendra Ramadhani <jrjuarendra@gmail.com>
 *
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
 * You should have received a copy of the GNU General Public License
 * along with this program.  If not, see <http://www.gnu.org/licenses/>.
*/
#pragma once

//#include "config_common.h"
#define MATRIX_ROWS  4
#define MATRIX_COLS  4

#define WEAR_LEVELING_LOGICAL_SIZE 4096
#define WEAR_LEVELING_BACKING_SIZE 8192
#define DYNAMIC_KEYMAP_MACRO_COUNT 32


#define MIDI_ADVANCED

// wiring of each half
#define MATRIX_ROW_PINS       { A6, A7, B0, B12 }
#define MATRIX_COL_PINS       { A2, A3, A4, A5 } // A virtual pin is needed for the encoder key matrix in via.

//#define MATRIX_ROW_PINS       { A6, A7, B0, C13 }
//#define MATRIX_COL_PINS       { A5, A1, A2, A3, A4, NO_PIN, NO_PIN} // A virtual pin is needed for the encoder key matrix in via.


#define DIODE_DIRECTION COL2ROW

#define TAP_CODE_DELAY  10
#define TAPPING_TERM 200
/* Debounce reduces chatter (unintended double-presses) - set 0 if debouncing is not needed */
#define DEBOUNCE 5
#define ENCODERS_PAD_A { B4 , A15}
#define ENCODERS_PAD_B { B3 , B1}
#define ENCODER_RESOLUTIONS       { 4 , 4}
/* disable these deprecated features by default */

/* ws2812 RGB LED */
#define WS2812_DI_PIN B14 //D3 - underglow C7 - backlight
#define RGBLED_NUM 10    // Number of L

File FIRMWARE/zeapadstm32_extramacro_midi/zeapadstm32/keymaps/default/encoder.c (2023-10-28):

#ifdef ENCODER_ENABLE
    static uint8_t encoder_state[2] = {0};
    //Use these keymap positions to specify the encoder functions on rotate.
    static keypos_t encoder_ccw[2] = {{4, 0}, {4, 2}};
    static keypos_t encoder_cw[2] = {{4, 1}, {4, 3}};

    void encoder_action_unregister(void) {
        for (int index = 0; index < 2; ++index) {
            if (encoder_state[index]) {
                keyevent_t encoder_event = (keyevent_t){.key = encoder_state[index] >> 1 ? encoder_cw[index] : encoder_ccw[index], .pressed = false, .time = (timer_read() | 1)};
                encoder_state[index] = 0;
                action_exec(encoder_event);
            }
        }
    }

    void encoder_action_register(uint8_t index, bool clockwise) {
        keyevent_t encoder_event = (keyevent_t){.key = clockwise ? encoder_cw[index] : encoder_ccw[index], .pressed = true, .time = (timer_read() | 1)};
        encoder_state[index] = (clockwise ^ 1) | (clockwise << 1);
        action_exec(encoder_event);
    }

    void matrix_scan_user(void) { encoder_action_unregister(); }

    bool encoder_update_user(uint8_t index, bool clockwise) {
        encoder_action_register(index, clockwise);
        return false;
    };
#endif

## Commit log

2024-06-14 FIX: fix folder name
    [config.h, encoder.c, keymap.c]
2024-06-15 FIX: fix bug on firmware extera macro
    [config.h]
2024-08-08 FEAT: add stl file for stand
    [Revised_Keyboard_Stand_Legs_v02 (5) (1).stl, Revised_Keyboard_Stand_Legs_v02 (5).stl, Support (1) (1).stl]
2025-03-15 FIX: fix name layer
    [keymap.c]

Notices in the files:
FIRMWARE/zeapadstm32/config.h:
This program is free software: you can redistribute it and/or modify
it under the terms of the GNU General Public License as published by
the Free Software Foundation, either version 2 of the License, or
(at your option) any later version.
